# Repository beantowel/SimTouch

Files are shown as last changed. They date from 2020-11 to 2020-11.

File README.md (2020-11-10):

# An attempt to make a Capacitive Touch Screen Stimulator

This project attempts to build a device which simulates human finger touch on a capacitive touch screen. We used two high-speed double diodes to build a switch which controls the connection between the conductive surface and the ground. If "the resistance be extremely high and the parasitic capacitance extremely low in the OFF state", then the induced equivalent capacitance would be very small, thus the touch screen won't detect it.

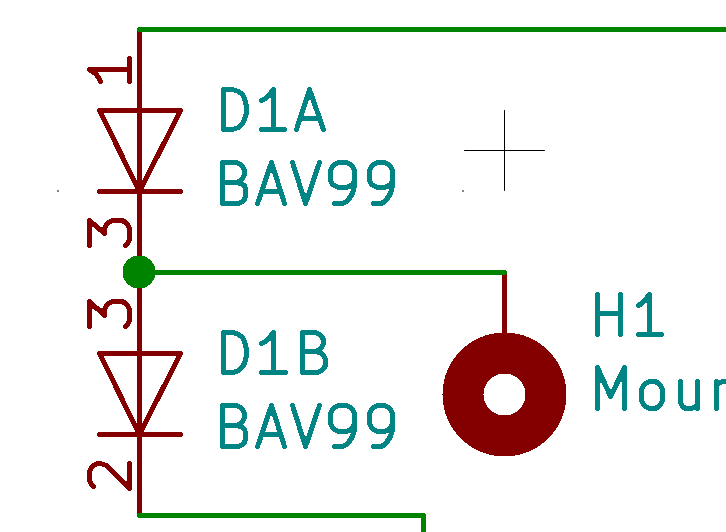
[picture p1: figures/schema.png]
schema


We built an array of these switches in a PCB, so we can use an MCU to control the stimulation in a 2-D plane.

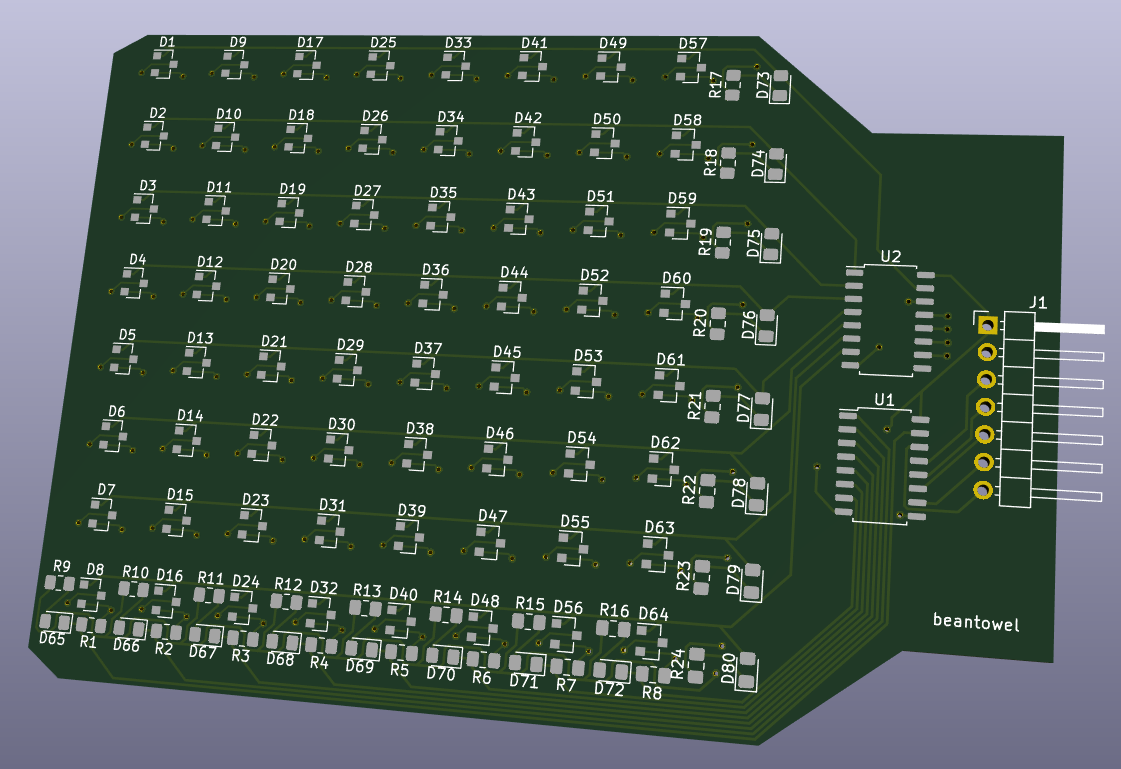
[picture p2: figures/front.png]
front

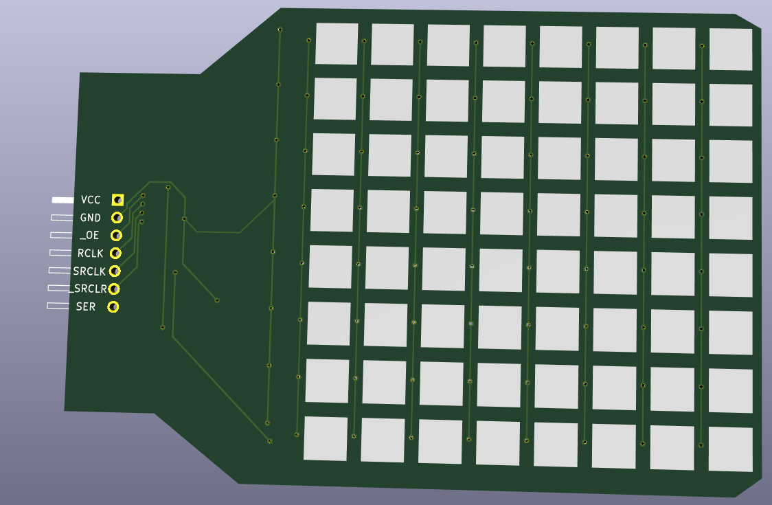
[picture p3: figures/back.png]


By using PWM, we tried to reach higher resolution with limited conductive pads, since the area of these pads needs to be large to gain enough capacitance.

touch
draw
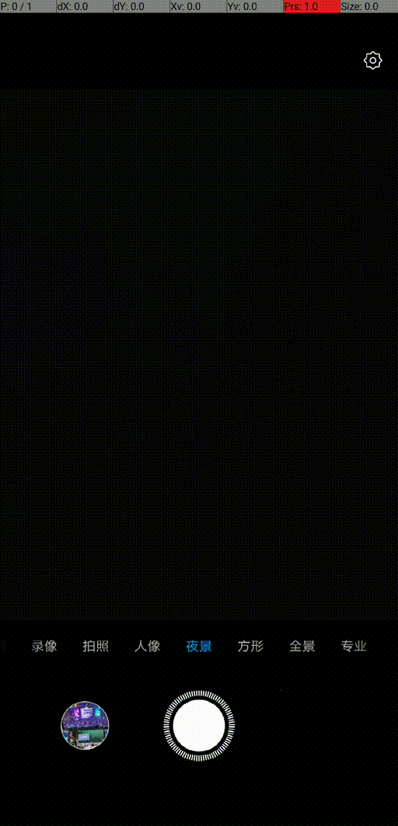
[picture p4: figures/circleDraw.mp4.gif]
circleDraw


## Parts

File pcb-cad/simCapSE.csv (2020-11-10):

Source: | /home/beantowel/FDU/miscellaneous/SimCap/PCB_Cad/simCap/simCapSE.sch
Date: | 2019年06月14日 星期五 19时30分03秒
Tool: | Eeschema 5.1.2-f72e74a~84~ubuntu18.04.1
Generator: | /usr/share/kicad/plugins/bom_csv_grouped_by_value_with_fp.py
Component Count: | 171
Ref | Qnty | Value | Cmp name | Footprint | Description | Vendor
D1, D2, D3, D4, D5, D6, D7, D8, D9, D10, D11, D12, D13, D14, D15, D16, D17, D18, D19, D20, D21, D22, D23, D24, D25, D26, D27, D28, D29, D30, D31, D32, D33, D34, D35, D36, D37, D38, D39, D40, D41, D42, D43, D44, D45, D46, D47, D48, D49, D50, D51, D52, D53, D54, D55, D56, D57, D58, D59, D60, D61, D62, D63, D64, | 64 | BAV99 | BAV99 | Package_TO_SOT_SMD:SOT-23 | BAV99 High-speed switching diodes
D77, D78, D79, D80, D73, D74, D75, D76, D69, D70, D71, D72, D65, D66, D67, D68, | 16 | LED | LED | LED_SMD:LED_0805_2012Metric_Pad1.15x1.40mm_HandSolder | Light emitting diode
H1, H2, H3, H4, H5, H6, H7, H8, H9, H10, H11, H12, H13, H14, H15, H16, H17, H18, H19, H20, H21, H22, H23, H24, H25, H26, H27, H28, H29, H30, H31, H32, H33, H34, H35, H36, H37, H38, H39, H40, H41, H42, H43, H44, H45, H46, H47, H48, H49, H50, H51, H52, H53, H54, H55, H56, H57, H58, H59, H60, H61, H62, H63, H64, | 64 | MountingHole_Pad | MountingHole_Pad | myfootprint:TCH_PAD | Mounting Hole with connection
J1, | 1 | Conn_01x07 | Conn_01x07 | Connector_PinHeader_2.54mm:PinHeader_1x07_P2.54mm_Horizontal | Generic connector, single row, 01x07, script generated (kicad-library-utils/schlib/autogen/connector/)
R9, R10, R11, R12, R13, R14, R15, R16, R17, R18, R19, R20, R21, R22, R23, R24, R1, R2, R3, R4, R5, R6, R7, R8, | 24 | R_Small | R_Small | Resistor_SMD:R_0805_2012Metric_Pad1.15x1.40mm_HandSolder | Resistor, small symbol
U2, U1, | 2 | 74HC595 | 74HC595 | Package_SO:SOP-16_4.55x10.3mm_P1.27mm | 8-bit serial in/out Shift Register 3-State Outputs

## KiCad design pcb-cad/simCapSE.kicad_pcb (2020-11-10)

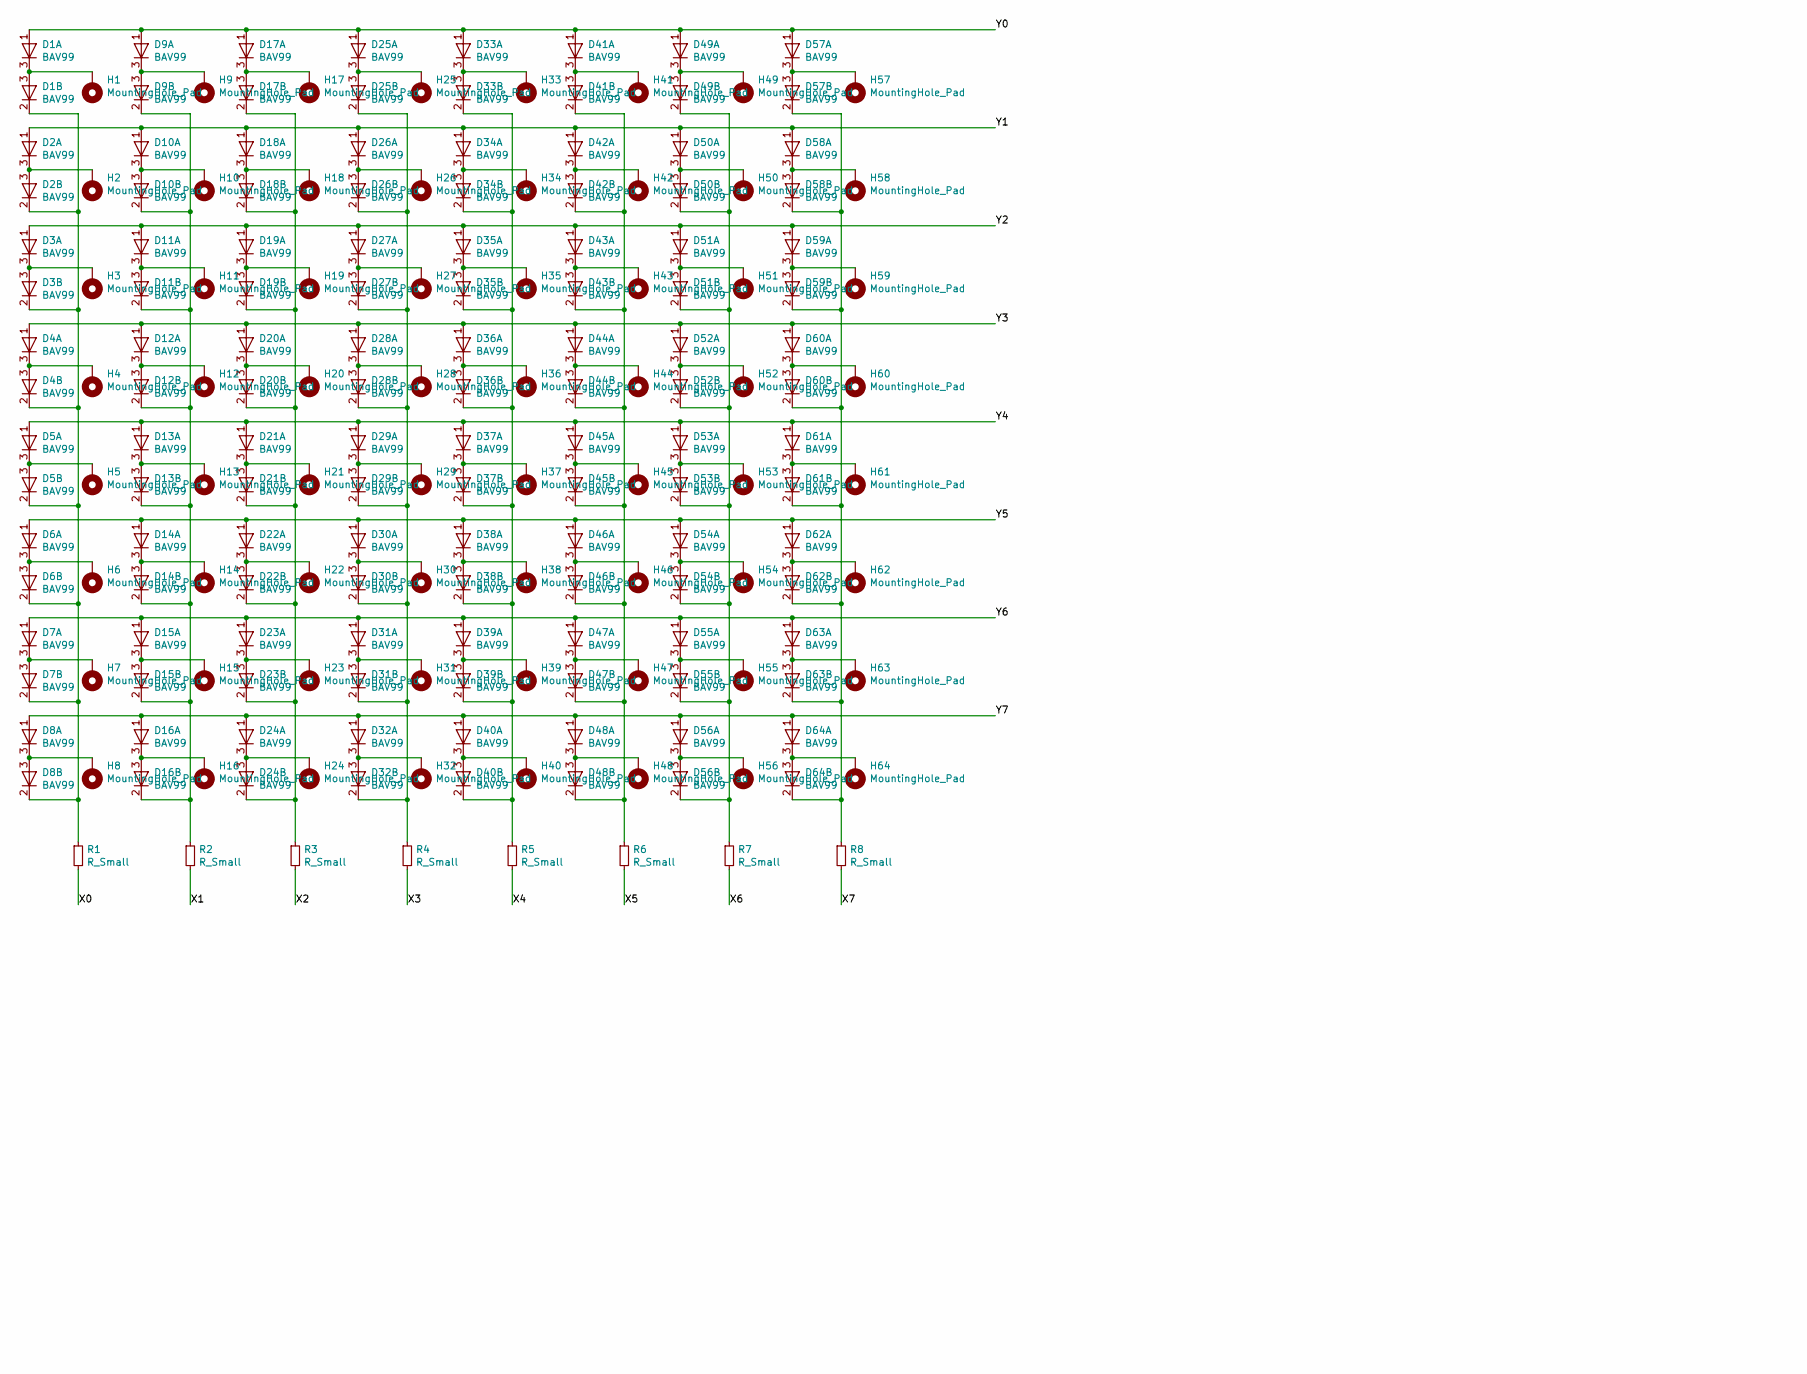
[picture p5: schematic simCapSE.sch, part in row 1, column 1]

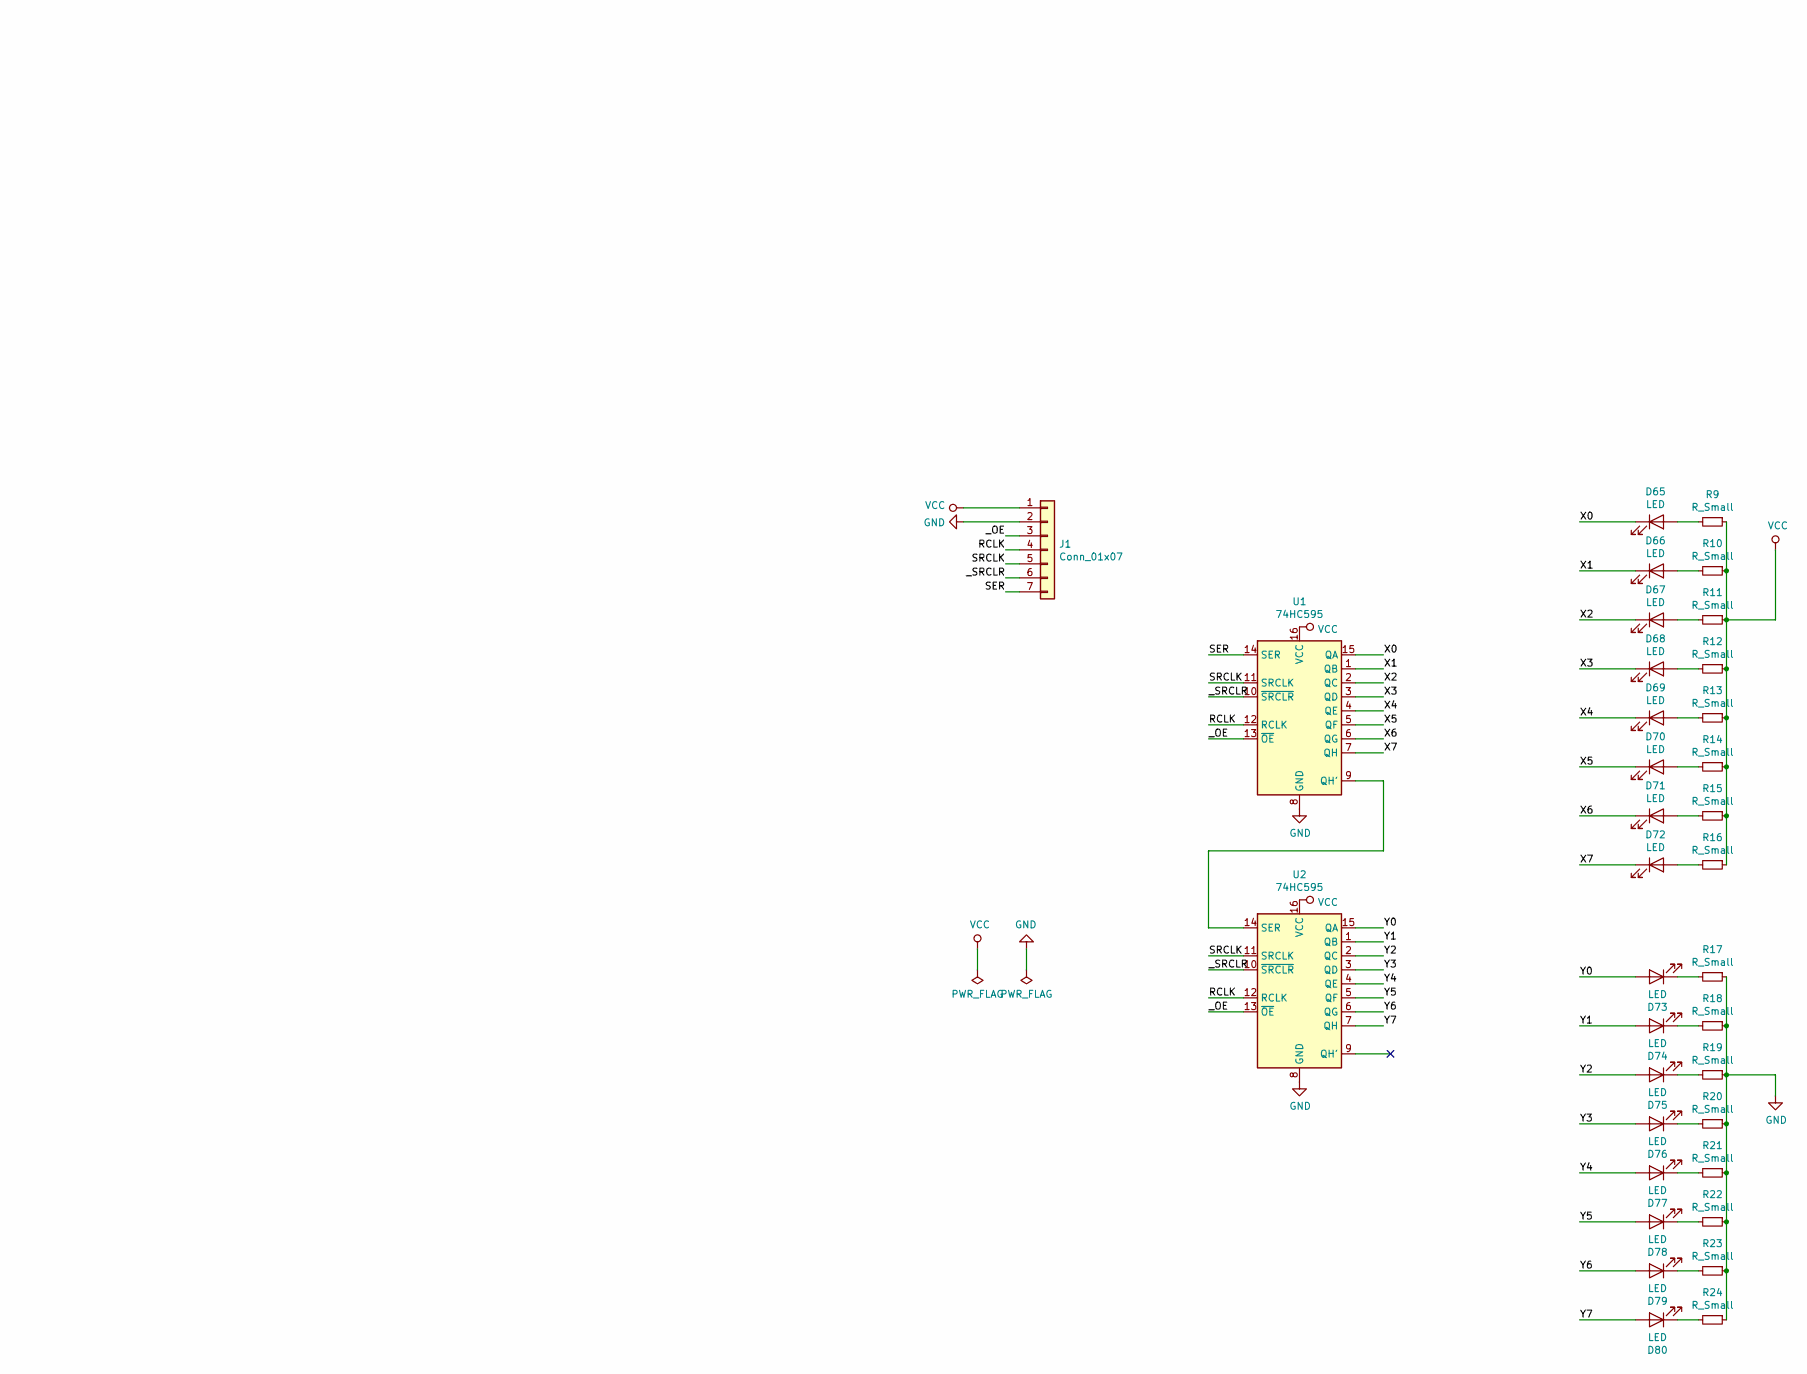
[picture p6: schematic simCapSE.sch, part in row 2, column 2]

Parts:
D1, D2, D3, D4, D5, D6, D7, D8, D9, D10, D11, D12, D13, D14, D15, D16, D17, D18, D19, D20, D21, D22, D23, D24, D25, D26, D27, D28, D29, D30, D31, D32, D33, D34, D35, D36, D37, D38, D39, D40, D41, D42, D43, D44, D45, D46, D47, D48, D49, D50, D51, D52, D53, D54, D55, D56, D57, D58, D59, D60, D61, D62, D63, D64: BAV99; SOT-23
D65, D66, D67, D68, D69, D70, D71, D72, D73, D74, D75, D76, D77, D78, D79, D80: LED; LED_0805_2012Metric_Pad1.15x1.40mm_HandSolder
H1, H2, H3, H4, H5, H6, H7, H8, H9, H10, H11, H12, H13, H14, H15, H16, H17, H18, H19, H20, H21, H22, H23, H24, H25, H26, H27, H28, H29, H30, H31, H32, H33, H34, H35, H36, H37, H38, H39, H40, H41, H42, H43, H44, H45, H46, H47, H48, H49, H50, H51, H52, H53, H54, H55, H56, H57, H58, H59, H60, H61, H62, H63, H64: MountingHole_Pad; TCH_PAD
J1: Conn_01x07; PinHeader_1x07_P2.54mm_Horizontal
R1, R2, R3, R4, R5, R6, R7, R8, R9, R10, R11, R12, R13, R14, R15, R16, R17, R18, R19, R20, R21, R22, R23, R24: R_Small; R_0805_2012Metric_Pad1.15x1.40mm_HandSolder
U1, U2: 74HC595; SOP-16_4.55x10.3mm_P1.27mm

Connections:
/RCLK: J1.4, U1.12 (RCLK), U2.12 (RCLK)
/SER: J1.7, U1.14 (SER)
/SRCLK: J1.5, U1.11 (SRCLK), U2.11 (SRCLK)
/X0: D65.1 (K), R1.2, U1.15 (QA)
/X1: D66.1 (K), R2.2, U1.1 (QB)
/X2: D67.1 (K), R3.2, U1.2 (QC)
/X3: D68.1 (K), R4.2, U1.3 (QD)
/X4: D69.1 (K), R5.2, U1.4 (QE)
/X5: D70.1 (K), R6.2, U1.5 (QF)
/X6: D71.1 (K), R7.2, U1.6 (QG)
/X7: D72.1 (K), R8.2, U1.7 (QH)
/Y0: D1.1 (A), D9.1 (A), D17.1 (A), D25.1 (A), D33.1 (A), D41.1 (A), D49.1 (A), D57.1 (A), D73.2 (A), U2.15 (QA)
/Y1: D2.1 (A), D10.1 (A), D18.1 (A), D26.1 (A), D34.1 (A), D42.1 (A), D50.1 (A), D58.1 (A), D74.2 (A), U2.1 (QB)
/Y2: D3.1 (A), D11.1 (A), D19.1 (A), D27.1 (A), D35.1 (A), D43.1 (A), D51.1 (A), D59.1 (A), D75.2 (A), U2.2 (QC)
/Y3: D4.1 (A), D12.1 (A), D20.1 (A), D28.1 (A), D36.1 (A), D44.1 (A), D52.1 (A), D60.1 (A), D76.2 (A), U2.3 (QD)
/Y4: D5.1 (A), D13.1 (A), D21.1 (A), D29.1 (A), D37.1 (A), D45.1 (A), D53.1 (A), D61.1 (A), D77.2 (A), U2.4 (QE)
/Y5: D6.1 (A), D14.1 (A), D22.1 (A), D30.1 (A), D38.1 (A), D46.1 (A), D54.1 (A), D62.1 (A), D78.2 (A), U2.5 (QF)
/Y6: D7.1 (A), D15.1 (A), D23.1 (A), D31.1 (A), D39.1 (A), D47.1 (A), D55.1 (A), D63.1 (A), D79.2 (A), U2.6 (QG)
/Y7: D8.1 (A), D16.1 (A), D24.1 (A), D32.1 (A), D40.1 (A), D48.1 (A), D56.1 (A), D64.1 (A), D80.2 (A), U2.7 (QH)
/_OE: J1.3, U1.13 (~OE), U2.13 (~OE)
/_SRCLR: J1.6, U1.10 (~SRCLR), U2.10 (~SRCLR)
GND: J1.2, R17.1, R18.1, R19.1, R20.1, R21.1, R22.1, R23.1, R24.1, U1.8 (GND), U2.8 (GND)
unnamed: D1.2 (K), D2.2 (K), D3.2 (K), D4.2 (K), D5.2 (K), D6.2 (K), D7.2 (K), D8.2 (K), R1.1
unnamed: D1.3 (K), H1.1
unnamed: D2.3 (K), H2.1
unnamed: D3.3 (K), H3.1
unnamed: D4.3 (K), H4.1
unnamed: D5.3 (K), H5.1
unnamed: D6.3 (K), H6.1
unnamed: D7.3 (K), H7.1
unnamed: D8.3 (K), H8.1
unnamed: D9.3 (K), H9.1
unnamed: D9.2 (K), D10.2 (K), D11.2 (K), D12.2 (K), D13.2 (K), D14.2 (K), D15.2 (K), D16.2 (K), R2.1
unnamed: D10.3 (K), H10.1
unnamed: D11.3 (K), H11.1
unnamed: D12.3 (K), H12.1
unnamed: D13.3 (K), H13.1
unnamed: D14.3 (K), H14.1
unnamed: D15.3 (K), H15.1
unnamed: D16.3 (K), H16.1
unnamed: D17.2 (K), D18.2 (K), D19.2 (K), D20.2 (K), D21.2 (K), D22.2 (K), D23.2 (K), D24.2 (K), R3.1
unnamed: D17.3 (K), H17.1
unnamed: D18.3 (K), H18.1
unnamed: D19.3 (K), H19.1
unnamed: D20.3 (K), H20.1
unnamed: D21.3 (K), H21.1
unnamed: D22.3 (K), H22.1
unnamed: D23.3 (K), H23.1
unnamed: D24.3 (K), H24.1
unnamed: D25.2 (K), D26.2 (K), D27.2 (K), D28.2 (K), D29.2 (K), D30.2 (K), D31.2 (K), D32.2 (K), R4.1
unnamed: D25.3 (K), H25.1
unnamed: D26.3 (K), H26.1
unnamed: D27.3 (K), H27.1
unnamed: D28.3 (K), H28.1
unnamed: D29.3 (K), H29.1
unnamed: D30.3 (K), H30.1
unnamed: D31.3 (K), H31.1
unnamed: D32.3 (K), H32.1
unnamed: D33.2 (K), D34.2 (K), D35.2 (K), D36.2 (K), D37.2 (K), D38.2 (K), D39.2 (K), D40.2 (K), R5.1
unnamed: D33.3 (K), H33.1
unnamed: D34.3 (K), H34.1
unnamed: D35.3 (K), H35.1
unnamed: D36.3 (K), H36.1
unnamed: D37.3 (K), H37.1
unnamed: D38.3 (K), H38.1
unnamed: D39.3 (K), H39.1
unnamed: D40.3 (K), H40.1
unnamed: D41.2 (K), D42.2 (K), D43.2 (K), D44.2 (K), D45.2 (K), D46.2 (K), D47.2 (K), D48.2 (K), R6.1
unnamed: D41.3 (K), H41.1
unnamed: D42.3 (K), H42.1
unnamed: D43.3 (K), H43.1
unnamed: D44.3 (K), H44.1
unnamed: D45.3 (K), H45.1
unnamed: D46.3 (K), H46.1
unnamed: D47.3 (K), H47.1
unnamed: D48.3 (K), H48.1
unnamed: D49.2 (K), D50.2 (K), D51.2 (K), D52.2 (K), D53.2 (K), D54.2 (K), D55.2 (K), D56.2 (K), R7.1
unnamed: D49.3 (K), H49.1
unnamed: D50.3 (K), H50.1
unnamed: D51.3 (K), H51.1
unnamed: D52.3 (K), H52.1
unnamed: D53.3 (K), H53.1
unnamed: D54.3 (K), H54.1
unnamed: D55.3 (K), H55.1
unnamed: D56.3 (K), H56.1
unnamed: D57.2 (K), D58.2 (K), D59.2 (K), D60.2 (K), D61.2 (K), D62.2 (K), D63.2 (K), D64.2 (K), R8.1
unnamed: D57.3 (K), H57.1
unnamed: D58.3 (K), H58.1
unnamed: D59.3 (K), H59.1
unnamed: D60.3 (K), H60.1
unnamed: D61.3 (K), H61.1
unnamed: D62.3 (K), H62.1
unnamed: D63.3 (K), H63.1
unnamed: D64.3 (K), H64.1
unnamed: D65.2 (A), R9.2
unnamed: D66.2 (A), R10.2
unnamed: D67.2 (A), R11.2
unnamed: D68.2 (A), R12.2
unnamed: D69.2 (A), R13.2
unnamed: D70.2 (A), R14.2
unnamed: D71.2 (A), R15.2
unnamed: D72.2 (A), R16.2
unnamed: D73.1 (K), R17.2
unnamed: D74.1 (K), R18.2
unnamed: D75.1 (K), R19.2
unnamed: D76.1 (K), R20.2
unnamed: D77.1 (K), R21.2
unnamed: D78.1 (K), R22.2
unnamed: D79.1 (K), R23.2
unnamed: D80.1 (K), R24.2
unnamed: U1.9 (QH'), U2.14 (SER)
VCC: J1.1, R9.1, R10.1, R11.1, R12.1, R13.1, R14.1, R15.1, R16.1, U1.16 (VCC), U2.16 (VCC)

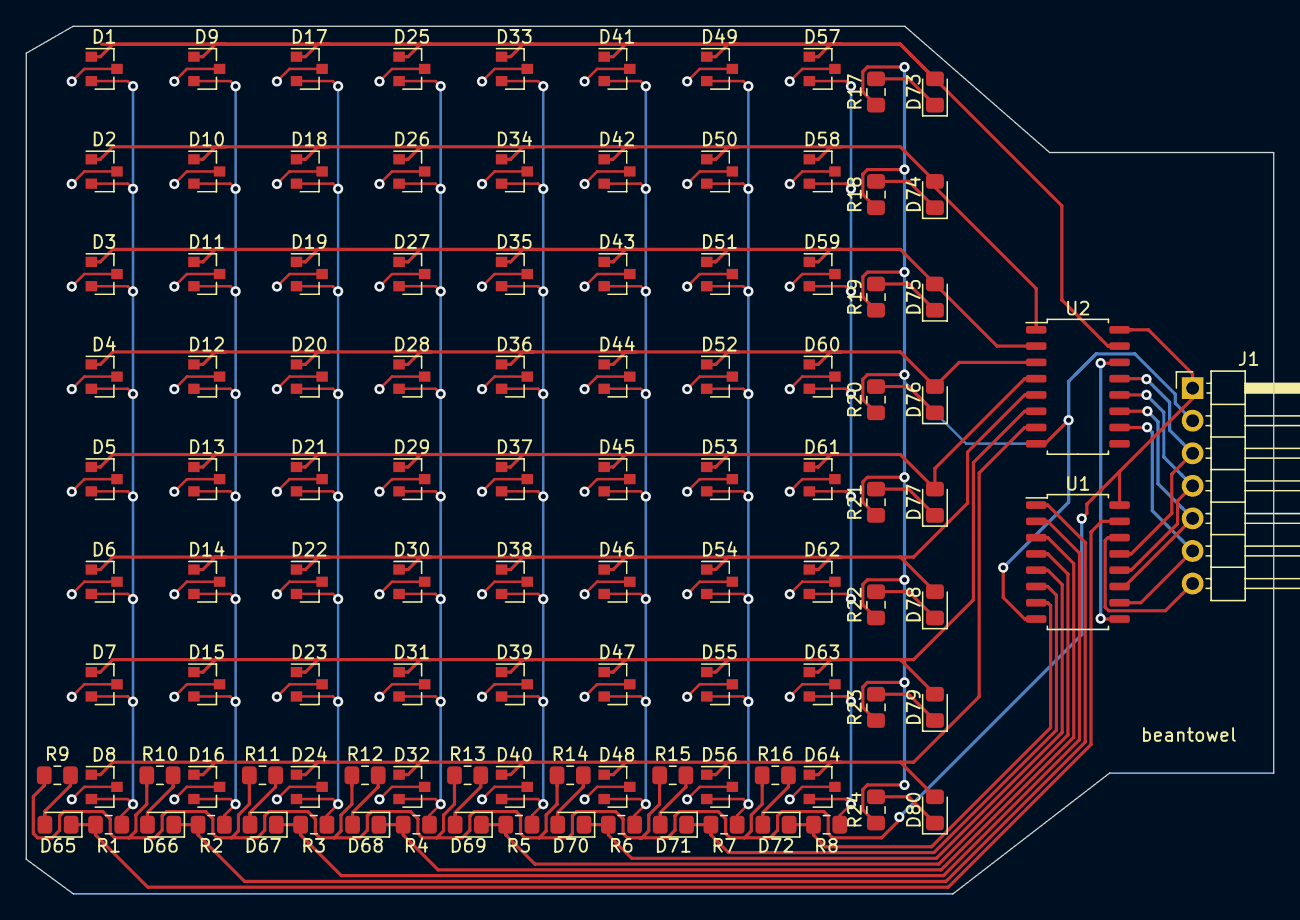
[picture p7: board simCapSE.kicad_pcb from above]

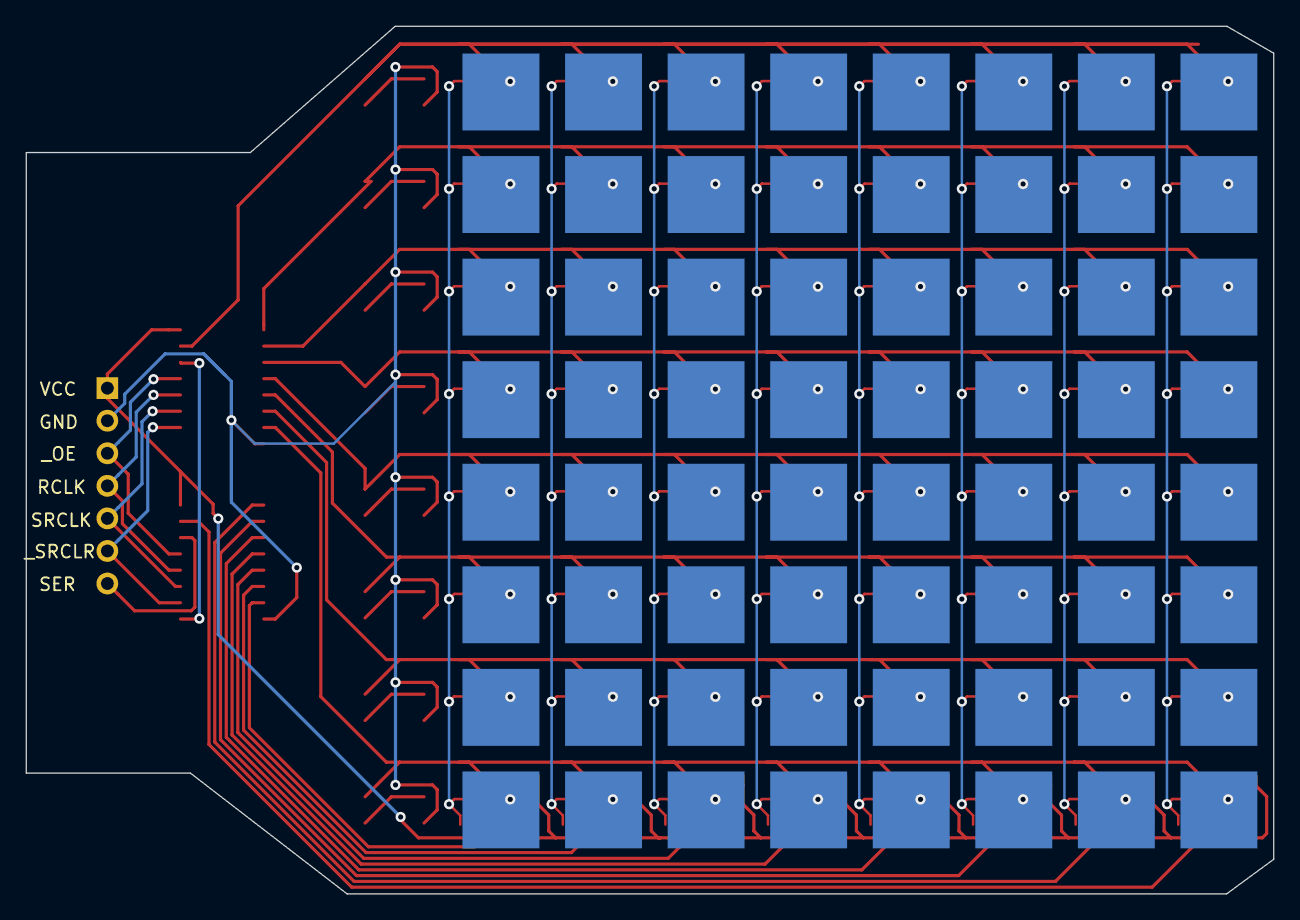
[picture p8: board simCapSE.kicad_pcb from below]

Board: 2 copper layers, 97.3 x 67.7 mm, 171 parts (64 on the bottom side), 112 nets.

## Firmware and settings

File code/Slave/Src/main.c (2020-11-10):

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

/* Includes ------------------------------------------------------------------*/
#include "main.h"
#include "usb_device.h"

/* USER CODE BEGIN Includes */
#include "touch_driver.h"
/* USER CODE END Includes */


void SystemClock_Config(void);
static void MX_GPIO_Init(void);
/**
 * @brief  The application entry point.
 * @retval int
 */
int main(void) {
  /* MCU Configuration--------------------------------------------------------*/

  /* Reset of all peripherals, Initializes the Flash interface and the Systick.
   */
  HAL_Init();

  /* Configure the system clock */
  SystemClock_Config();

  /* Initialize all configured peripherals */
  MX_GPIO_Init();
  MX_USB_DEVICE_Init();
  /* USER CODE BEGIN 2 */
  HAL_GPIO_WritePin(GPIOC, GPIO_PIN_13, GPIO_PIN_RESET); // led on
  TCH_Driver_Init(&tchBoard, GPIOA, GPIO_PIN_1, GPIO_PIN_2, GPIO_PIN_3,
                  GPIO_PIN_4, GPIO_PIN_5);
  HAL_Delay(1000);
  HAL_GPIO_WritePin(GPIOC, GPIO_PIN_13, GPIO_PIN_SET); // led off
  /* USER CODE END 2 */

  /* Infinite loop */
  /* USER CODE BEGIN WHILE */
  while (1) {
    TCH_Start();
    /* USER CODE END WHILE */

    /* USER CODE BEGIN 3 */
  }
  /* USER CODE END 3 */
}

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


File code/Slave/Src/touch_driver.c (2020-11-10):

/**
 *
 * Driver for touch simulation
 * control shift register whose output make address of a capacity matrix
 *
 ******************************************************************************
 */

#include "touch_driver.h"
#include "usbd_def.h"
#include <stdlib.h>
#include <string.h>

#define RX_RING_SIZE 16 // APP_RX_DATA_SIZE
#define CONCAT_BYTE(lo, hi) ((uint16_t)((lo) + ((hi) << 8)))

#define SET 0xFF   // SET <buffer data>*2 <duty>*2
#define TOUCH 0xFE // TOUCH <duration>
#define SLEEP 0xFD // SLEEP <duration>
#define DRAW 0xFC  // DRAW <new duty>*2 <duration>

// <buffer data> 8-bit shift register chain:
// reverse(<Col_0>-...-<Col_n>-<Row_0>-...-<Row_n>)
static uint8_t receiveBufRing[RX_RING_SIZE][USB_FS_MAX_PACKET_SIZE];
static uint32_t receiveLenRing[RX_RING_SIZE];
static uint16_t ringBegin, ringEnd;
TCH_BOARD tchBoard;

void TCH_Parse_Command();
void flushPos(TCH_BOARD *board, uint8_t col_duty, uint8_t row_duty);
// void outputEnable(TCH_BOARD *board, uint8_t state);
void clearReg(TCH_BOARD *board);
void pwmTouch(TCH_BOARD *board, uint32_t duration);
void pwmDraw(TCH_BOARD *board, uint8_t ncol_duty, uint8_t nrow_duty,
             uint32_t duration);

void TCH_Driver_Init(TCH_BOARD *board, GPIO_TypeDef *GPIOx, uint16_t _oe,
                     uint16_t rclk, uint16_t srclk, uint16_t _srclr,
                     uint16_t ser) {
  board->GPIO_group = GPIOx;
  board->_OE_PIN = _oe;
  board->RCLK_PIN = rclk;
  board->SRCLK_PIN = srclk;
  board->_SRCLR_PIN = _srclr;
  board->SER_PIN = ser;
  board->col_duty = 0;
  board->row_duty = 0;
  board->outputBufHi =
      (uint8_t *)malloc(sizeof(uint8_t) * TCHBOARD_OUTPUT_BUF_SIZE);
  board->outputBufLo =
      (uint8_t *)malloc(sizeof(uint8_t) * TCHBOARD_OUTPUT_BUF_SIZE);
  ringBegin = 0;
  ringEnd = 0;
  memset(receiveBufRing, 0, sizeof(receiveBufRing));
  memset(receiveLenRing, 0, sizeof(receiveLenRing));
}

uint8_t TCH_Receive_Callback(uint8_t *Buf, uint32_t Len) {
  memcpy(receiveBufRing[ringEnd], Buf, Len);
  receiveLenRing[ringEnd] = Len;
  ringEnd = (ringEnd + 1) % RX_RING_SIZE;
  return 0;
}

void TCH_Start() { TCH_Parse_Command(); }

void TCH_Parse_Command() {
  while (ringBegin != ringEnd) {
    uint8_t *receiveBuf = receiveBufRing[ringBegin];
    uint32_t i = 0, len = receiveLenRing[ringBegin];
    uint16_t duration;
    TCH_BOARD *board = &tchBoard;
    while (i < len) {
      HAL_GPIO_WritePin(GPIOC, GPIO_PIN_13, GPIO_PIN_RESET); // led on
      switch (receiveBuf[i]) {
      case SET:
        memcpy(board->outputBufHi, &receiveBuf[i + 1],
               TCHBOARD_OUTPUT_BUF_SIZE);
        memcpy(board->outputBufLo,
               &receiveBuf[i + 1 + TCHBOARD_OUTPUT_BUF_SIZE],
               TCHBOARD_OUTPUT_BUF_SIZE);
        board->col_duty = receiveBuf[i + 1 + 2 * TCHBOARD_OUTPUT_BUF_SIZE];
        board->row_duty = receiveBuf[i + 1 + 2 * TCHBOARD_OUTPUT_BUF_SIZE + 1];
        i += 1 + 2 * TCHBOARD_OUTPUT_BUF_SIZE + 2;
        break;
      case TOUCH:
        duration = CONCAT_BYTE(receiveBuf[i + 1], receiveBuf[i + 2]);
        pwmTouch(board, duration);
        i += 1 + 2;
        break;
      case SLEEP:
        duration = CONCAT_BYTE(receiveBuf[i + 1], receiveBuf[i + 2]);
        HAL_Delay(duration);
        i += 1 + 2;
        break;
      case DRAW:
        duration = CONCAT_BYTE(receiveBuf[i + 3], receiveBuf[i + 4]);
        pwmDraw(board, receiveBuf[i + 1], receiveBuf[i + 2], duration);
        i += 1 + 2 + 2;
        break;
      default:
        i++;
        break;
      }
      HAL_GPIO_WritePin(GPIOC, GPIO_PIN_13, GPIO_PIN_SET); // led off
    }
    ringBegin = (ringBegin + 1) % RX_RING_SIZE;
  }
}

void flushPos(TCH_BOARD *board, uint8_t col_duty, uint8_t row_duty) {
  for (uint16_t cycle = 0; cycle < 0xFF; cycle += 0x10) {
    clearReg(board);
    for (uint16_t i = 0; i < TCHBOARD_OUTPUT_BUF_SIZE; i++) {
      uint8_t byte;
      if (i < (TCHPAD_ROWS / 8)) {
        byte = cycle < row_duty ? board->outputBufHi[i] : board->outputBufLo[i];
      } else {
        byte = cycle < col_duty ? board->outputBufHi[i] : board->outputBufLo[i];
        // active-low output for column selection
        byte = ~byte;
      }
      // write to shift register
      for (uint16_t j = 0; j < 8; j++) {
        // flip bits for MSB order
        uint8_t bit = byte & (1 << (7 - j));
        HAL_GPIO_WritePin(board->GPIO_group, board->SRCLK_PIN,
                          GPIO_PIN_RESET); // CLK: 0
        HAL_GPIO_WritePin(board->GPIO_group, board->SER_PIN, bit);
        HAL_GPIO_WritePin(board->GPIO_group, board->SRCLK_PIN,
                          GPIO_PIN_SET); // CLK: ↑
      }
    }
    // add bubble because shift register state is one clock pulse ahead of the
    // storage(latch) register
    HAL_GPIO_WritePin(board->GPIO_group, board->RCLK_PIN,
                      GPIO_PIN_RESET); // CLK: 0
    HAL_GPIO_WritePin(board->GPIO_group, board->SER_PIN, GPIO_PIN_RESET);
    HAL_GPIO_WritePin(board->GPIO_group, board->RCLK_PIN,
                      GPIO_PIN_SET); // CLK ↑
  }
}

void clearReg(TCH_BOARD *board) {
  HAL_GPIO_WritePin(board->GPIO_group, board->_SRCLR_PIN,
                    GPIO_PIN_RESET); // enable, clear reg
  HAL_GPIO_WritePin(board->GPIO_group, board->_SRCLR_PIN,
                    GPIO_PIN_SET); // disable
}

uint32_t deltaTick(uint32_t now, uint32_t pre) {
  if (now >= pre) {
    return now - pre;
  } else {
    // 24 bit sys tick
    return (1 << 24) - pre + now;
  }
}

void pwmTouch(TCH_BOARD *board, uint32_t duration) {
  uint32_t check_time = HAL_GetTick();
  while (deltaTick(HAL_GetTick(), check_time) < duration) {
    flushPos(board, board->col_duty, board->row_duty);
  }
  // close output
  clearReg(board);
  for (uint16_t i = 0; i < TCHPAD_COLS / 8; i++) {
    for (uint16_t j = 0; j < 8; j++) {
      HAL_GPIO_WritePin(board->GPIO_group, board->SRCLK_PIN,
                        GPIO_PIN_RESET); // CLK: 0
      HAL_GPIO_WritePin(board->GPIO_group, board->SER_PIN, 1);
      HAL_GPIO_WritePin(board->GPIO_group, board->SRCLK_PIN,
                        GPIO_PIN_SET); // CLK: ↑
    }
  }
  HAL_GPIO_WritePin(board->GPIO_group, board->RCLK_PIN,
                    GPIO_PIN_RESET); // CLK: 0
  HAL_GPIO_WritePin(board->GPIO_group, board->SER_PIN, GPIO_PIN_RESET);
  HAL_GPIO_WritePin(board->GPIO_group, board->RCLK_PIN,
                    GPIO_PIN_SET); // CLK ↑
}

void pwmDraw(TCH_BOARD *board, uint8_t ncol_duty, uint8_t nrow_duty,
             uint32_t duration) {
  uint32_t check_time = HAL_GetTick();
  for (uint32_t dt = 0; dt < duration;
       dt = deltaTick(HAL_GetTick(), check_time)) {
    uint8_t col_duty =
        board->col_duty + (ncol_duty - board->col_duty) * dt / duration;
    uint8_t row_duty =
        board->row_duty + (nrow_duty - board->row_duty) * dt / duration;
    flushPos(board, col_duty, row_duty);
  }
}

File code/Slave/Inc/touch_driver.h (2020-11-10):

/**
 *
 * Driver for touch simulation
 * control shift register whose output make address of a capacity matrix
 *
 ******************************************************************************
 */

#ifndef __TOUCH_DRIVER__H__
#define __TOUCH_DRIVER__H__

#ifdef __cplusplus
extern "C" {
#endif

#include "stm32f1xx_hal.h"

#define TCHPAD_COLS 8
#define TCHPAD_ROWS 8
#define TCHBOARD_OUTPUT_BUF_SIZE (((TCHPAD_COLS) + (TCHPAD_ROWS)) / 8)

typedef struct _TCH_BOARD {
  // 74HC595 pins
  // 8-Bit Serial-Input/Serial or Parallel-Output ShiftRegister with Latched
  // 3-State Outputs RCLK: latch clock, SRCLK: shiftRegister clock
  GPIO_TypeDef *GPIO_group;
  uint16_t _OE_PIN, RCLK_PIN, SRCLK_PIN, _SRCLR_PIN, SER_PIN;
  uint8_t col_duty, row_duty;
  uint8_t *outputBufHi, *outputBufLo;
} TCH_BOARD;
extern TCH_BOARD tchBoard;

void TCH_Driver_Init(TCH_BOARD *board, GPIO_TypeDef *GPIOx, uint16_t _oe,
                     uint16_t rclk, uint16_t srclk, uint16_t _srclr,
                     uint16_t ser);
uint8_t TCH_Receive_Callback(uint8_t *Buf, uint32_t Len);
void TCH_Start();

#ifdef __cplusplus
}
#endif

#endif /* __TOUCH_DRIVER__H__ */

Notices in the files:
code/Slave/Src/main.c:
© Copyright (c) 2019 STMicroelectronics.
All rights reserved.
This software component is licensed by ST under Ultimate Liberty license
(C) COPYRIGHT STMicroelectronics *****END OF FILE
